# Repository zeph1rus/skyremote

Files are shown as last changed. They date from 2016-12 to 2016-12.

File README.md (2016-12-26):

# skyremote
Building An Accessible Sky remote with Arduino Mega

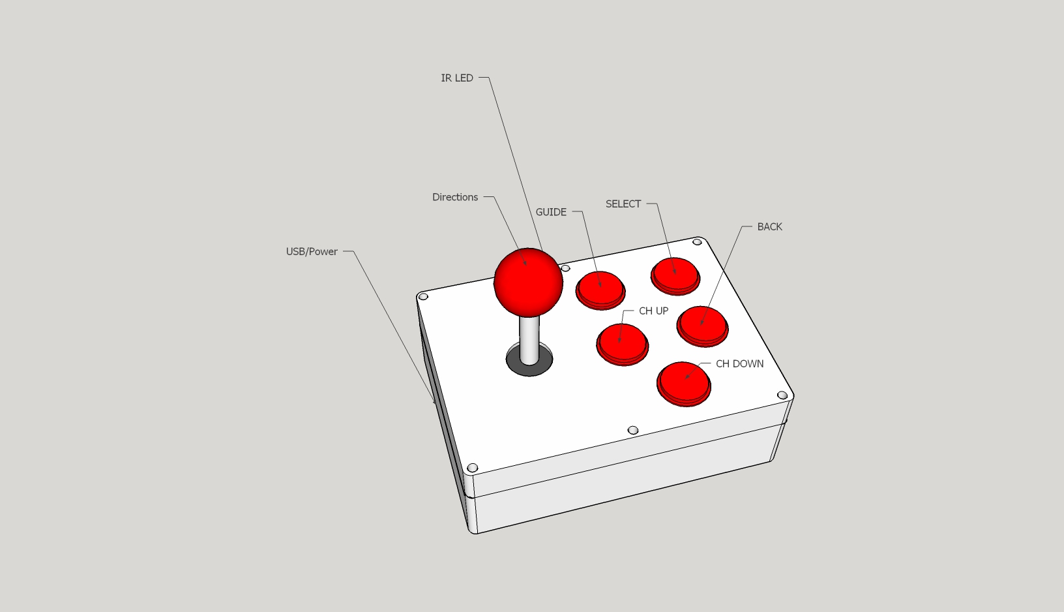
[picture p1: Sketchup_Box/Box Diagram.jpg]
Diagram
Sketchup Diagram: 

This project builds a Sky Remote suitable for a user with limited fine motor controls (sutch as users with MS or other degenerative nerve conditions. It was conceived to help my father operate the  TV, once his fine movement left him unable to operate a standard (or even traditional 'accessible') remote.

This project uses an Arduino Mega processor, however any Arduino board compatible with the IRremote library and enough digital inputs for your buttons will suffice.  The mega is admittedly overkill for the functionality required. 

##Dependencies:

* An arduino board! - One supported by the IRremote library - see: [link](https://github.com/z3t0/Arduino-IRremote)
* Aformentioned library selected for your sketch. 
* Switches and a joystick, I recommend Arcade joysticks and switches as they have very definite actions, but require little force to actuate. They are also widely available. 
* An IR LED and appropriate current limiting resistor for it. You can desolder from an existing remote if you want, however I suggest you keep a working remote around for the equipment.
* Wires, Wiring tools and soldering equipment.  A lot of switches come with Spade connectors which may be more flexible to solder to than the switches directly.
* An appropriate enclosure, 
* A Step drill will be useful to drill holes in the enclosure for the switches and joystick. 

##Example Wiring Diagram

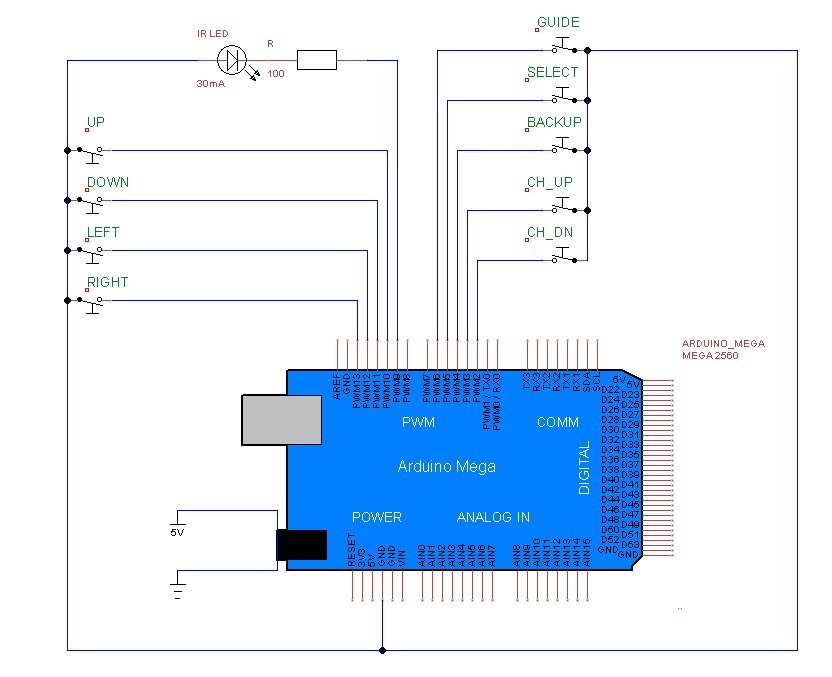
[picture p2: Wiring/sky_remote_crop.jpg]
TinyCAD wiring diagram
TinyCad: 

##Credits

### I used the fantasic IRremote library for Arduino, without which this would not have been possible. [Arduino IRremote](https://github.com/z3t0/Arduino-IRremote)
### hexreader at the Edaboard forums for this post detailing reverse engineering of the Sky Plus remove codes: [Edaboards](http://www.edaboard.com/thread299046.html#post1279512)
### The SB-Projects detailing of the RC6 Protocol [RC6](http://www.sbprojects.com/knowledge/ir/rc6.php)

##Appendix:

I have detailed the remote codes from the post linked above here in case this goes down. I've only implemented the ones I require in the header file, however it will be simple to add/remove as you need. 

```Sky+ commander buttons - cover closed
00c00-00c09    0 to 9
00c0c	       	 on/off
00c20			ch+
00c21				ch-
00c24					pause
00c28						fast forward
00c3c						     text
00c3d							rewind
00c3e								play
00c3f									stop
00c40										record
00c58											up
00c59												down
00c5a													left
00c5b														right
00c5c															select
00c6d															 red
00c6e															  green
00c6f															   yellow
00c70															    blue
00c7d															     box office
00c7e															     	 services
00c80																  sky
00c81																   help
00c83																    backup
00ccb																     i
00ccc																      tv guide
00cf5																      	 interactive```

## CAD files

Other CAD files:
Sketchup_Box/Box Diagram.skp

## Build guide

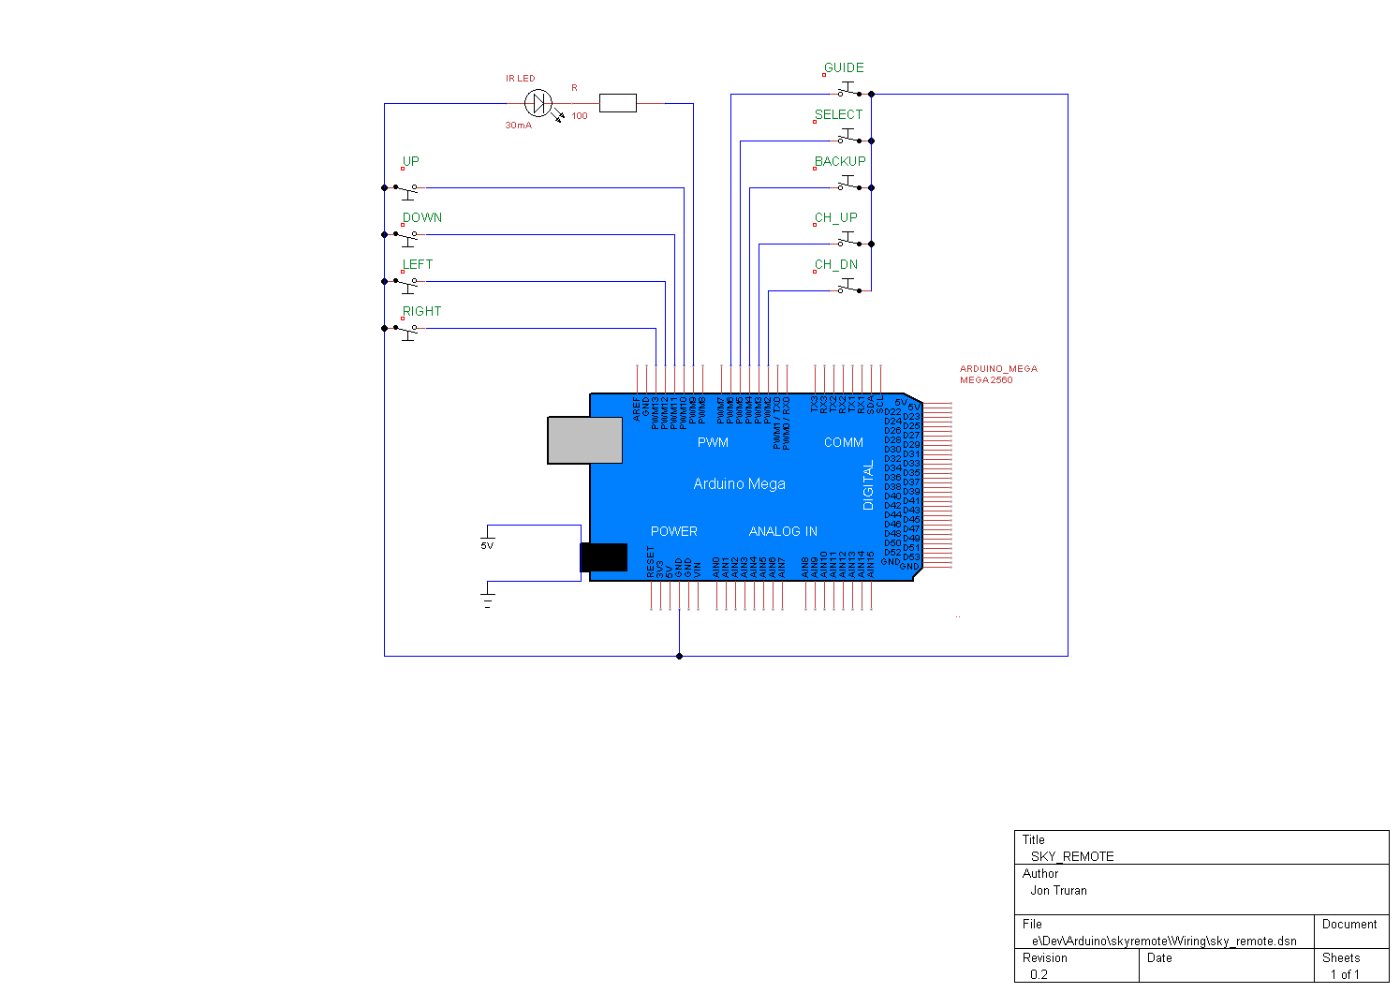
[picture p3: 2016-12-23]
Wiring/sky_remote.png

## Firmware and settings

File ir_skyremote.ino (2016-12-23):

#include <IRremote.h>
#include <IRremoteInt.h>
#include "ir_skyremote.h"


int sending = 0;
unsigned long lastsent;
IRsend irsend;


void setup()
{
  // Pin 9 is output for IR setup is done in the library
  pinMode(PIN_UP, INPUT_PULLUP);
  pinMode(PIN_DN, INPUT_PULLUP);
  pinMode(PIN_L, INPUT_PULLUP);
  pinMode(PIN_R, INPUT_PULLUP);
  pinMode(PIN_GUIDE, INPUT_PULLUP);
  pinMode(PIN_SELECT, INPUT_PULLUP);
  pinMode(PIN_BACKUP, INPUT_PULLUP);
  pinMode(PIN_CHUP, INPUT_PULLUP);
  pinMode(PIN_CHDN, INPUT_PULLUP);
  Serial.begin(9600);
  Serial.println("Setup Complete");
}

int scanKeys () {
  int keyscanned = 0;
  //scan_directions
  for ( int i = 10; i < 14 ; i++) {
    if (digitalRead(i) == LOW) {
      keyscanned = i;
    }
  }
  for ( int i = 2; i < 7 ; i++) {
    if (digitalRead(i) == LOW) {
      keyscanned = i;
    }
  }
  return keyscanned;
}

void sendSkyCode (unsigned long code) {
  for (int i = 0; i < 3; i++) {
    //RC6 requires we send the code three times
    //We send keyup event seperately once it's been released. 
    Serial.println("Sending Code");
    Serial.println(code,HEX);
    irsend.sendRC6(code, 24);
  }
  lastsent = code;
  sending = 1;
}

void sendSkyCodeOnce (unsigned long code) {
  Serial.println("Sending Code Once");
  Serial.println(code, HEX);
  irsend.sendRC6(code, 24);
}


void loop()
{

  switch (scanKeys()) {
    case PIN_UP:
      sendSkyCode(SKYPLUS_UP);
      break;
    case PIN_DN:
      sendSkyCode(SKYPLUS_DN);
      break;
    case PIN_L:
      sendSkyCode(SKYPLUS_L);
      break;
    case PIN_R:
      sendSkyCode(SKYPLUS_R);
      break;
    case PIN_GUIDE:
      sendSkyCode(SKYPLUS_GUIDE);
      break;
    case PIN_BACKUP:
      sendSkyCode(SKYPLUS_BACKUP);
      break;
    case PIN_CHUP:
      sendSkyCode(SKYPLUS_CHUP);
      break;
    case PIN_CHDN:
      sendSkyCode(SKYPLUS_CHDN);
      break;
    case PIN_SELECT:
      sendSkyCode(SKYPLUS_SELECT);
      
      break;
    case 0:
    default:
      /* Send code with bit 4 inverted, essentially 'keydown event' */
      if (sending == 1) {
        sendSkyCodeOnce(lastsent + INVERT_TOGGLE);
        sending = 0;
      }
      break;

  }
  delay(125);
}

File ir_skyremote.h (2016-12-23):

#define INVERT_TOGGLE 0x100000
//flips bit 4
#define SKYPLUS_UP 0xC00C58
#define SKYPLUS_DN 0xC00C59
#define SKYPLUS_L 0xC00C5A
#define SKYPLUS_R 0xC00C5B
#define SKYPLUS_GUIDE 0xC00CCC
#define SKYPLUS_BACKUP 0xC00C83
#define SKYPLUS_CHUP 0xC00C20
#define SKYPLUS_CHDN 0xC00C21
#define SKYPLUS_SELECT 0xC00C5C
#define PIN_UP 10
#define PIN_DN 11
#define PIN_L 13
#define PIN_R 12
#define PIN_GUIDE 5
#define PIN_SELECT 6
#define PIN_BACKUP 4
#define PIN_CHUP 3
#define PIN_CHDN 2
